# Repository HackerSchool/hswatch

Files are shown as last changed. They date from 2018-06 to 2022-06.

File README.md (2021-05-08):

# HSWatch

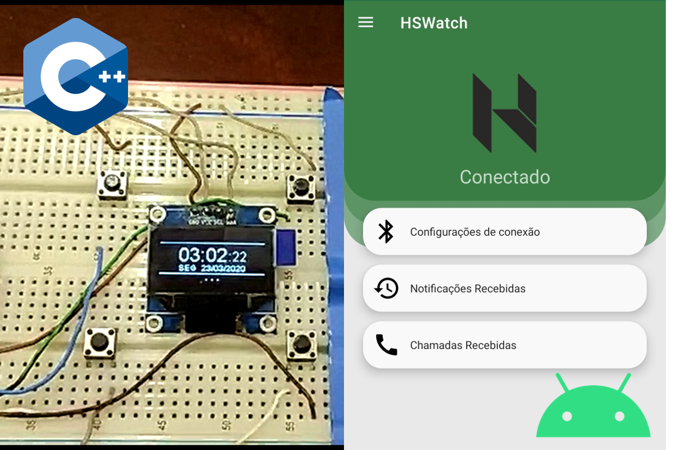
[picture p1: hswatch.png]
HSWatch


## Objective

This project aims to create a _diy_ smartwatch, open-source and programable using Arduino code style, so that hobbyists, students and hackers can contribute to this project and design their own smartwatch according to their tastes. Besides the watch it self this project also contains an Android companion app source code, that is also extendable so that the watch can accomodate more features.

## Features 

This are the features that are already implemented:
- Show a clock (hours, minutes, seconds, day, month, year, week day) regularly syncronized with the smartphone clock.
- Mirror notifications from the smartphone to the watch screen, vibrating each time a new one is received.
- Show notification history, blinking a RGB LED each time there is an unread message. (The LED blinks a diferent color for diferent types of notifications)
- Measure battery charge level of the smartwatch and show it on the main screen.
- Three adjustable alarm clocks. This alarms sound a buzzer and vibrate the watch.
- Stop watch and timer.
- Show 6 days weather forecast on watch screen, using the smartphone companion app as a gateway to online weather services.

The software was made to be easily extendable, feel free to add more features.

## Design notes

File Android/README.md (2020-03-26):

# HSWatch

GitHub para a aplicação HSWatch @ HackerSchool.

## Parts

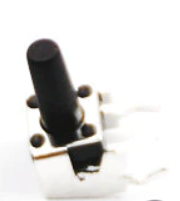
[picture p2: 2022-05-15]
docs/img/components/button.png

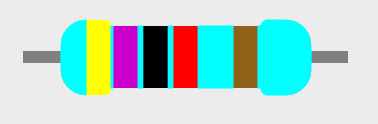
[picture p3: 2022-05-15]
docs/img/components/47kr.png

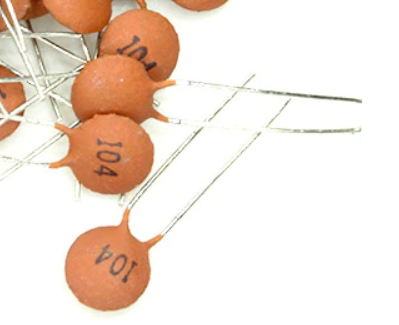
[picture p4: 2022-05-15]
docs/img/components/capacitor.png

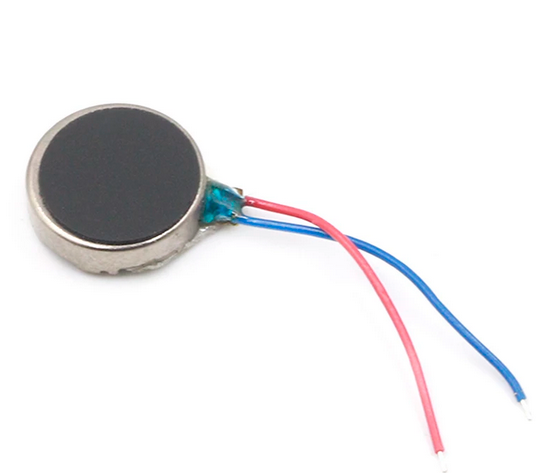
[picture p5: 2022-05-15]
docs/img/components/vibrator.png

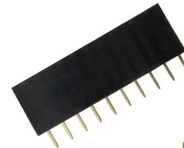
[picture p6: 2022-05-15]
docs/img/components/pin_header_ttgo.png

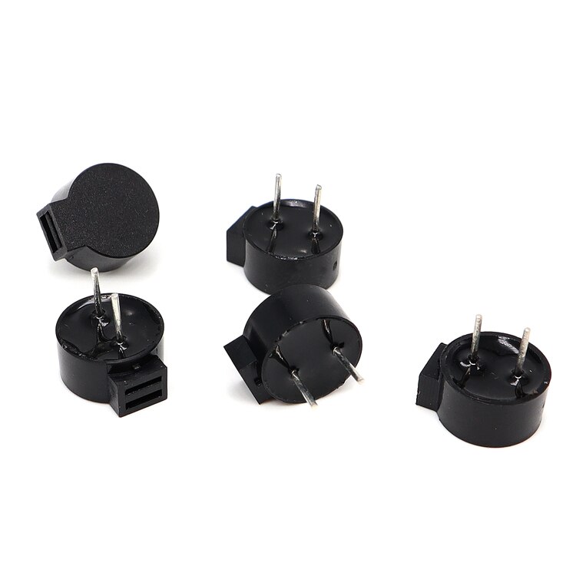
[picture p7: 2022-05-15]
docs/img/components/buzzer.jpg

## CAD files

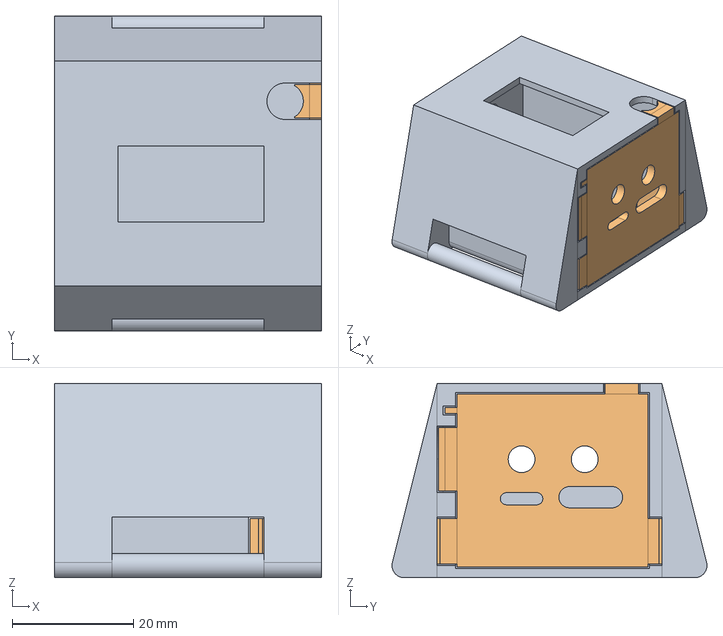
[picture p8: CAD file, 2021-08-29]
3D_Models/Assembly_hswatch.FCStd
44.0 x 51.9 x 32.0 mm
left
right (cover)

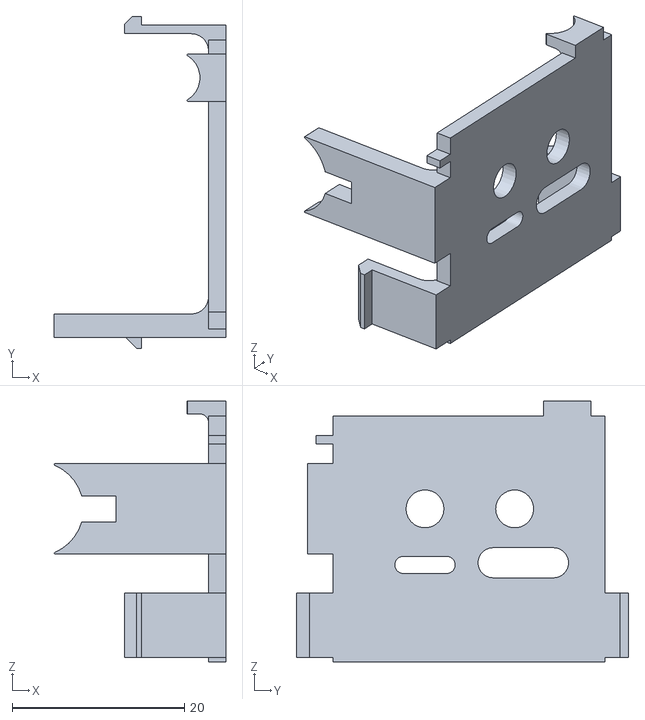
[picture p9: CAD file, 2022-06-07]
3D_Models/Case_Side_Right(Cover).stl
19.9 x 38.5 x 30.2

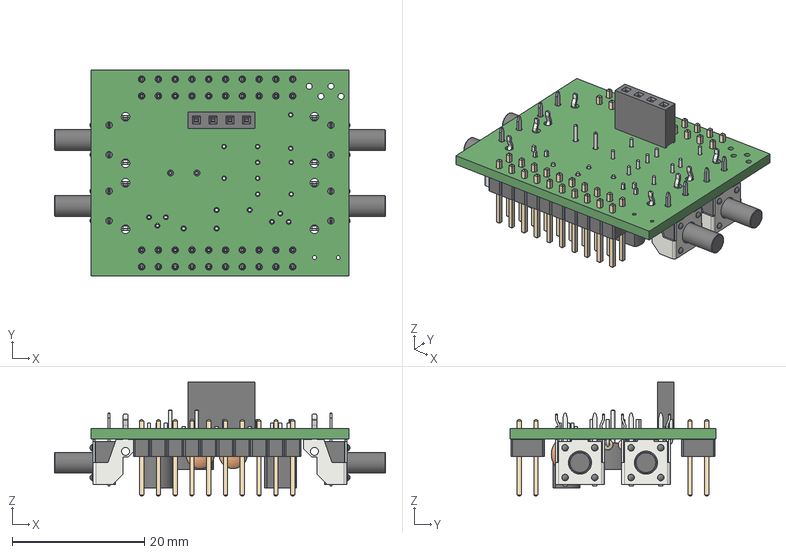
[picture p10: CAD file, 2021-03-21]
PCB/hswatch.step
50.1 x 31.2 x 17.2 mm

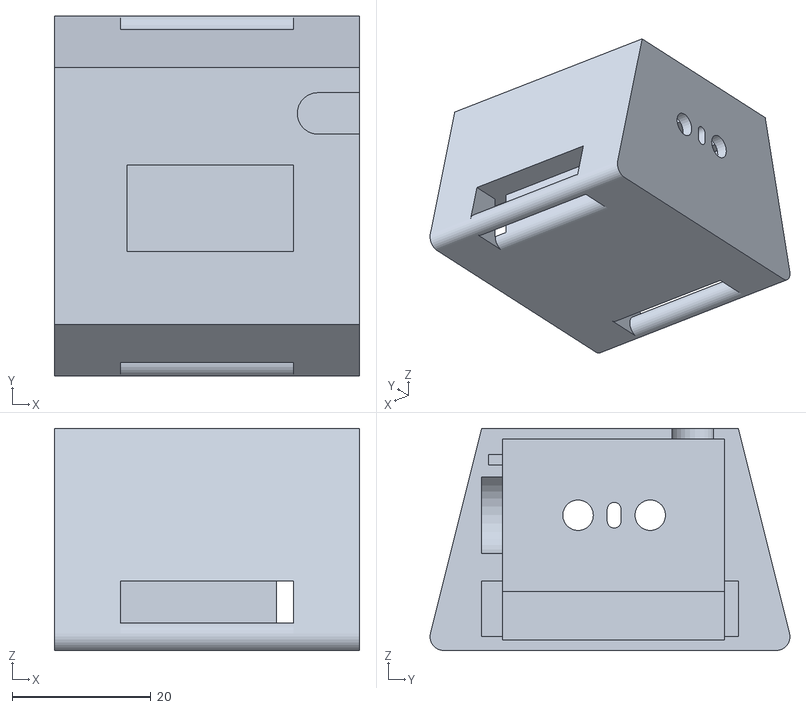
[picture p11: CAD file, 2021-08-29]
3D_Models/Case_Side_Left.stl
44.0 x 51.9 x 32.0

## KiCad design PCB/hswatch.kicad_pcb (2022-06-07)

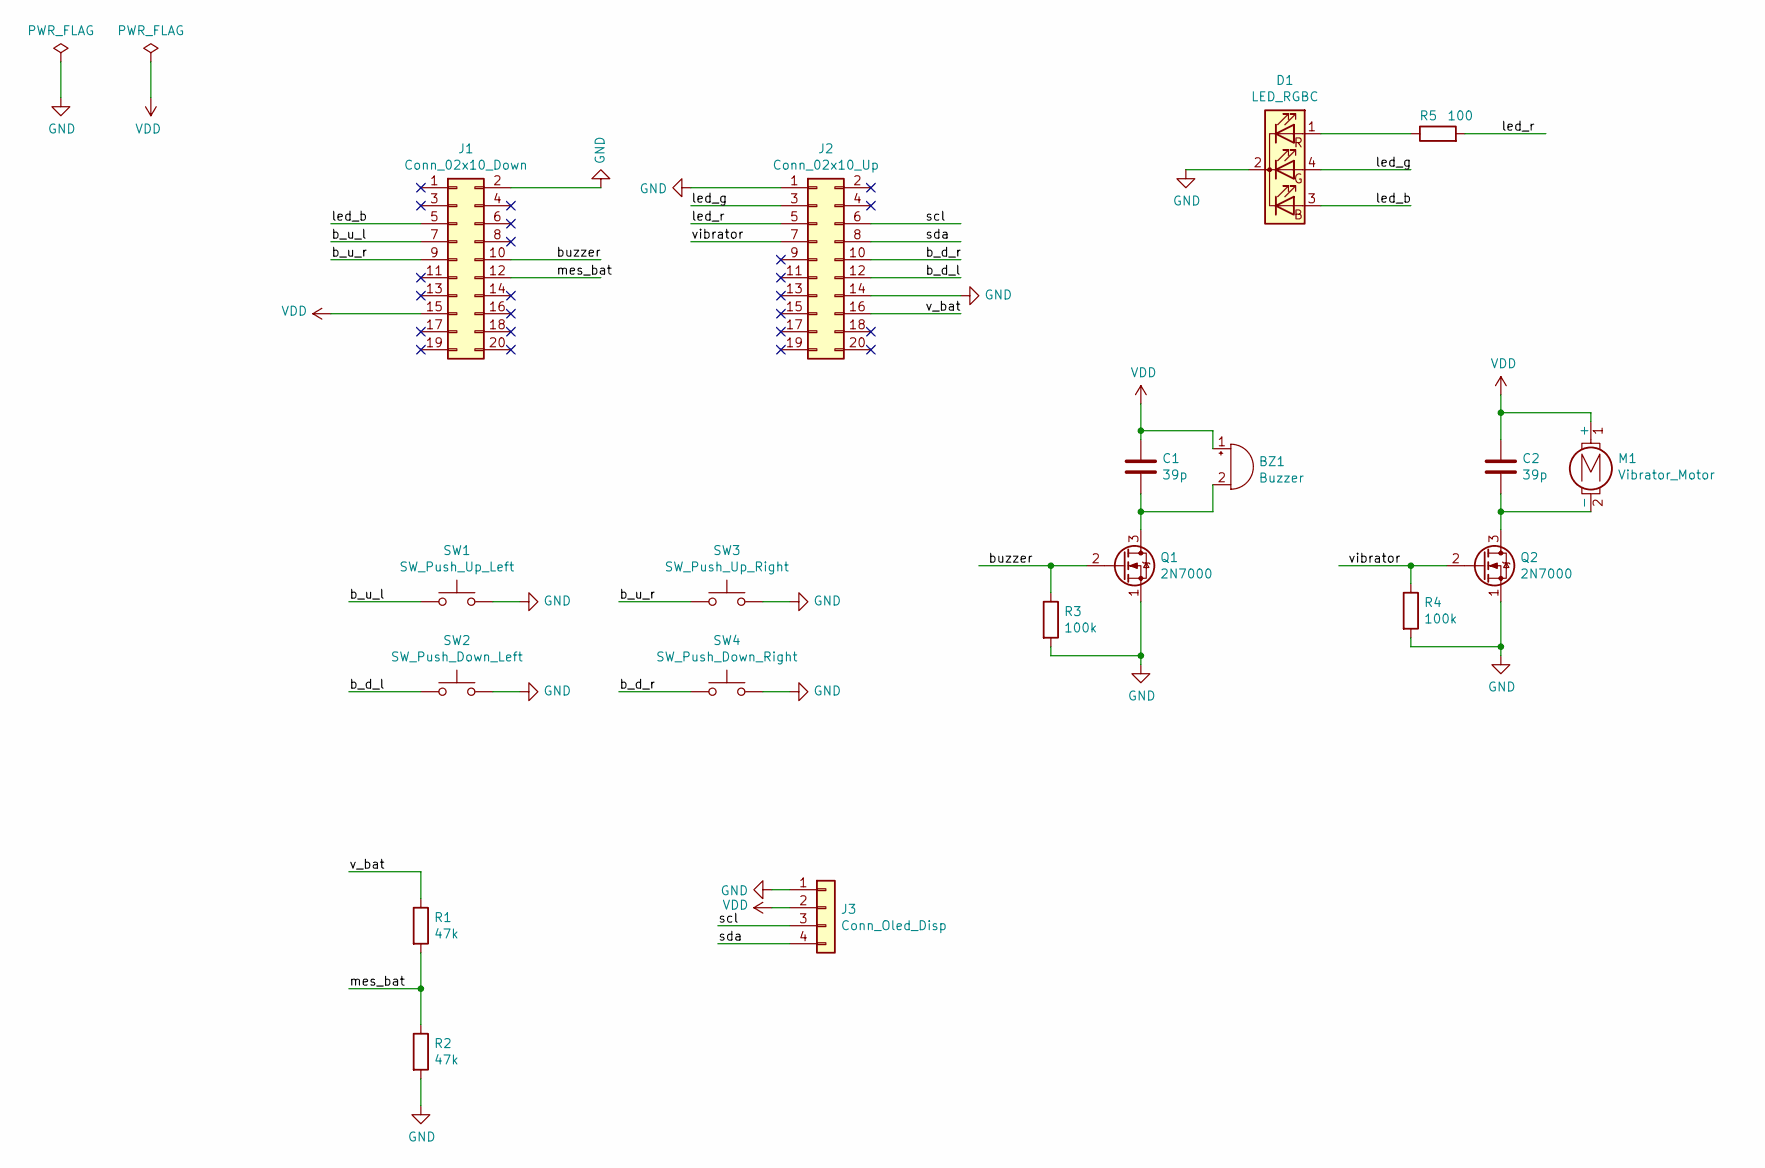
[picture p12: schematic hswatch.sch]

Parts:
BZ1: Buzzer; MagneticBuzzer_CUI_CST-931RP-A
C1, C2: 39p; C_Disc_D4.3mm_W1.9mm_P5.00mm
D1: LED_RGBC; LED_D5.0mm-4_RGB_Staggered_Pins
J1: Conn_02x10_Down; PinHeader_2x10_P2.54mm_Vertical
J2: Conn_02x10_Up; PinHeader_2x10_P2.54mm_Vertical
J3: Conn_Oled_Disp; PinSocket_1x04_P2.54mm_Vertical
M1: Vibrator_Motor; SolderWire-0.1sqmm_1x02_P3.6mm_D0.4mm_OD1mm
Q1, Q2: 2N7000; TO-92_HandSolder
R1, R2: 47k; R_Axial_DIN0204_L3.6mm_D1.6mm_P5.08mm_Horizontal
R3, R4: 100k; R_Axial_DIN0204_L3.6mm_D1.6mm_P5.08mm_Horizontal
R5: 100; R_Axial_DIN0204_L3.6mm_D1.6mm_P5.08mm_Horizontal
SW1: SW_Push_Up_Left; SW_Tactile_SPST_Angled_PTS645Vx83-2LFS
SW2: SW_Push_Down_Left; SW_Tactile_SPST_Angled_PTS645Vx83-2LFS
SW3: SW_Push_Up_Right; SW_Tactile_SPST_Angled_PTS645Vx83-2LFS
SW4: SW_Push_Down_Right; SW_Tactile_SPST_Angled_PTS645Vx83-2LFS

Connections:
/b_d_l: J2.12, SW2.1
/b_d_r: J2.10, SW4.1
/b_u_l: J1.7, SW1.1
/b_u_r: J1.9, SW3.1
/buzzer: J1.10, Q1.2 (G), R3.1
/led_b: D1.3 (BA), J1.5
/led_g: D1.4 (GA), J2.3
/led_r: J2.5, R5.2
/mes_bat: J1.12, R1.2, R2.1
/scl: J2.6, J3.3
/sda: J2.8, J3.4
/v_bat: J2.16, R1.1
/vibrator: J2.7, Q2.2 (G), R4.1
GND: D1.2 (K), J1.2, J2.1, J2.14, J3.1, Q1.1 (S), Q2.1 (S), R2.2, R3.2, R4.2, SW1.2, SW2.2, SW3.2, SW4.2
unnamed: BZ1.2 (+), C1.2, Q1.3 (D)
unnamed: C2.2, M1.2 (-), Q2.3 (D)
unnamed: D1.1 (RA), R5.1
VDD: BZ1.1 (-), C1.1, C2.1, J1.15, J3.2, M1.1 (+)

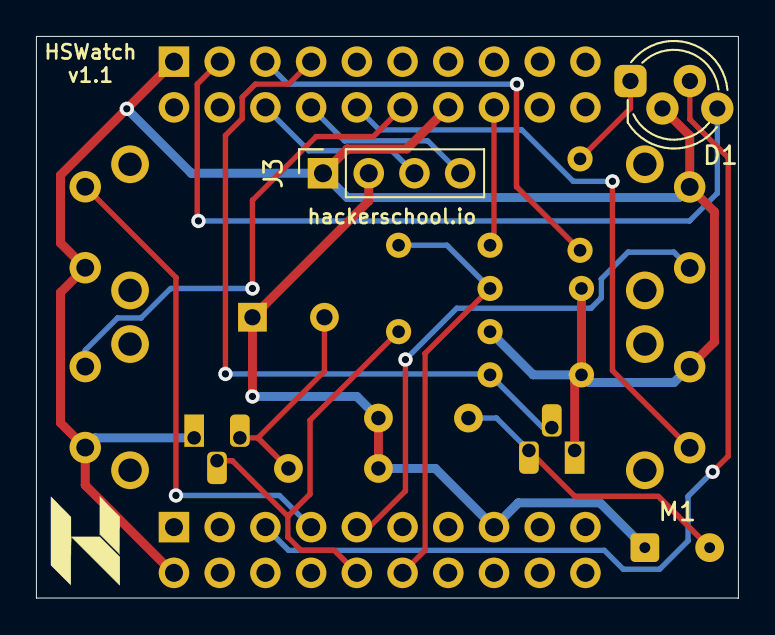
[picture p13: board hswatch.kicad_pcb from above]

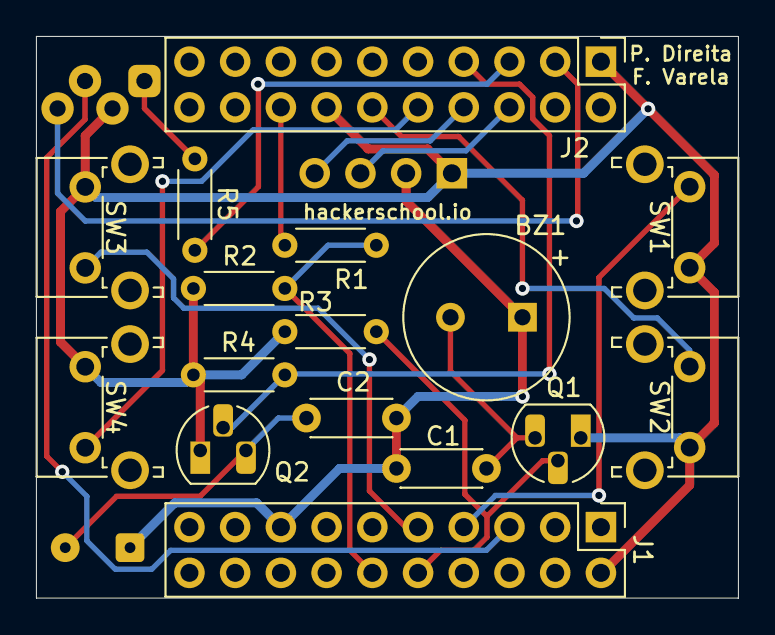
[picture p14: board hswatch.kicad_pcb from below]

Board: 2 copper layers, 39.0 x 31.2 mm, 19 parts (16 on the bottom side), 18 nets.

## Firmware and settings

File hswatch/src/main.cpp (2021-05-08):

#include <Arduino.h>
#include "communication.h"
#include "home.h"
#include "logo_hs.h"
#include <Wire.h>
#include <SSD1306Wire.h>
#include "queue_display.h"
#include "display.h"
#include "notification.h"
#include "menu.h"
#include "logo_app.h"
#include "vibrator.h"
#include "buzzer.h"
#include "led.h"
#include "app.h"
#include "battery.h"
#include "about.h"

//Include App go here
#include "timer.h"
#include "alarm.h"
#include "weather.h"
#include "flashlight.h"
#include "settings.h"

#define B_LEFT_UP 18
#define B_LEFT_DOWN 16
#define B_RIGHT_UP 19
#define B_RIGHT_DOWN 17

#define BT_BUFFER_SIZE 300
#define DEBOUNCE_TIME 50
#define DEBOUNCE_TIME2 50

TaskHandle_t bt_task_h, timer_task_h, b_left_up_task_h, b_left_down_task_h, b_right_up_task_h, b_right_down_task_h;

QueueHandle_t * queue_display;

hw_timer_t * timer = NULL;

SSD1306Wire screen(0x3c, SDA, SCL);

unsigned long debounce_left_up=0, debounce_left_down=0, debounce_right_up=0, debounce_right_down=0;

int number_of_times=0;
int number_of_times_r=0;

void bt_task(void*);
int init_display();
void IRAM_ATTR onTimer();
void timer_task(void*);

void IRAM_ATTR onPressBLeftUp();
void IRAM_ATTR onPressBLeftDown();
void IRAM_ATTR onPressBRightUp();
void IRAM_ATTR onPressBRightDown();
void b_left_up_task(void*);
void b_left_down_task(void*);
void b_right_up_task(void*);
void b_right_down_task(void*);


void setup() {

	Serial.begin(9600);

	pinMode(B_LEFT_UP, INPUT_PULLUP);
	pinMode(B_LEFT_DOWN, INPUT_PULLUP);
	pinMode(B_RIGHT_UP, INPUT_PULLUP);
	pinMode(B_RIGHT_DOWN, INPUT_PULLUP);

	init_bluetooth("HSWatch");
	init_led();
	init_display();
	init_vibrator();
	init_buzzer();
	init_battery();
	App::init_app();

	queue_display = new QueueHandle_t();

	*queue_display = xQueueCreate(15,sizeof(msg_queue_display));

	new Home("TIM","Home",NULL);
	new Notification("NOT","Notification",NULL);
	new About("Abo","About",NULL);
	
	//App Initialization goes here
	new Timer("CHR","Chronograph & Timer",logo_timer);
	new Alarm("ALA","Alarm", logo_alarm);
	new Weather("WEA","Weather", logo_weather);
	new FlashLight("FLA","Flashlight", logo_flashlight);
	new Settings("SET","Settings", logo_settings);
	
	new Menu("MEN","Menu",NULL);

	App::run_app("Home");

	xTaskCreate(bt_task,"bluetooth task",8192,NULL,1,&bt_task_h);
	xTaskCreate(timer_task,"timer task",8192,NULL,1,&timer_task_h);
	xTaskCreate(b_left_up_task,"button left up task",8192,NULL,1,&b_left_up_task_h);
	xTaskCreate(b_left_down_task,"button left down task",8192,NULL,1,&b_left_down_task_h);
	xTaskCreate(b_right_up_task,"button right up task",8192,NULL,1,&b_right_up_task_h);
	xTaskCreate(b_right_down_task,"button right down task",8192,NULL,1,&b_right_down_task_h);

	timer = timerBegin(0,80,true);
	timerAttachInterrupt(timer, &onTimer, true);
	timerAlarmWrite(timer, 1000000, true);
	timerAlarmEnable(timer);

	attachInterrupt(B_LEFT_UP, onPressBLeftUp, FALLING);
	attachInterrupt(B_LEFT_DOWN, onPressBLeftDown, FALLING);
	attachInterrupt(B_RIGHT_UP, onPressBRightUp, FALLING);
	attachInterrupt(B_RIGHT_DOWN, onPressBRightDown, FALLING);

}

void loop() {

	msg_queue_display msg;

	xQueueReceive(*queue_display, &msg, portMAX_DELAY);
	
	switch (msg.type)
	{
	case _clear:
		screen.clear();
		break;

	case _display:
		screen.display();
		break;

	case _drawRect:
		screen.drawRect(msg.a,msg.b,msg.c,msg.d);
		break;

	case _fillRect:
		screen.fillRect(msg.a,msg.b,msg.c,msg.d);
		break;

	case _drawHorizontalLine:
		screen.drawHorizontalLine(msg.a,msg.b,msg.c);
		break;
	
	case _drawString:
		screen.drawString(msg.a,msg.b,String(msg.s));
		break;

	case _drawStringMaxWidth:
		screen.drawStringMaxWidth(msg.a,msg.b,msg.c,String(msg.s));
		break;

	case _setTextAlignment:
		if(msg.a==0){
			screen.setTextAlignment(TEXT_ALIGN_LEFT);
		}else if(msg.a==1){
			screen.setTextAlignment(TEXT_ALIGN_CENTER);
		}else if(msg.a==2){
			screen.setTextAlignment(TEXT_ALIGN_RIGHT);
		}else{
			screen.setTextAlignment(TEXT_ALIGN_CENTER_BOTH);
		}
		break;

	case _drawXbm:
		screen.drawXbm(msg.a, msg.b, msg.c, msg.d, msg.image);
	
	default:
		if(msg.a==0){
			screen.setFont(ArialMT_Plain_10);
		}else if(msg.a==1){
			screen.setFont(ArialMT_Plain_16);
		}else{
			screen.setFont(ArialMT_Plain_24);
		}
		break;
	}
}

void bt_task(void* par_in){

	//Adafruit_SSD1306 * screen=(Adafruit_SSD1306 *)par_in;
	//init_display();
	Serial.println(App::app_search_by_id("TIM")->id);
	//App::app_search_by_id("TIM")->display();
	//screen->clear();
	//screen->display();
	//App::run_app("Home");
	Serial.println("ola");
	int len;
	char buf[BT_BUFFER_SIZE], aux[BT_BUFFER_SIZE]; 
	char *context, *m_id, delim[2]; 
	App* app_to_call;
	
	delim[0] = (char)0x03;
	delim[1] = '\0';

	while(1){
		len = receive_bt(buf,BT_BUFFER_SIZE);

		buf[len]='\0';
		Serial.print("buf=");
		Serial.println(buf);

		if(len<5)
			continue;

		strcpy(aux,buf+4);
		m_id = strtok_r(buf,delim,&context);

		if(m_id==NULL)
			continue;
		
		app_to_call = App::app_search_by_id(String(m_id));
		if(app_to_call!=NULL){
			app_to_call->bt_receive(aux);
		}
	}

}

int init_display(){

	Display::initDisplay();
	 
	screen.init();

	screen.flipScreenVertically();

	screen.clear();
	screen.drawXbm(
		(128  - LOGO_WIDTH ) / 2,
		(64 - LOGO_HEIGHT) / 2,
		LOGO_WIDTH, LOGO_HEIGHT, logo_hs);
	screen.display();
	delay(3000);

	return 0;
}

void IRAM_ATTR onTimer(){
	vTaskNotifyGiveFromISR(timer_task_h,NULL);
}

void timer_task(void*){
	while (1)
	{
		ulTaskNotifyTake(pdFALSE, portMAX_DELAY);
		App::call_timer();
		check_level_timer();
	}
}

void IRAM_ATTR onPressBLeftUp(){
	vTaskNotifyGiveFromISR(b_left_up_task_h,NULL);
}

void IRAM_ATTR onPressBLeftDown(){
	vTaskNotifyGiveFromISR(b_left_down_task_h,NULL);
}

void IRAM_ATTR onPressBRightUp(){
	vTaskNotifyGiveFromISR(b_right_up_task_h,NULL);
}

void IRAM_ATTR onPressBRightDown(){
	vTaskNotifyGiveFromISR(b_right_down_task_h,NULL);
}

void b_left_up_task(void*){
	while (1)
	{
		ulTaskNotifyTake(pdFALSE, portMAX_DELAY);

		if(millis()-DEBOUNCE_TIME>debounce_left_up){

			delay(DEBOUNCE_TIME2);

			if(!digitalRead(B_LEFT_UP)){

				debounce_left_up=millis();
				number_of_times++;
				Serial.print("L: ");
				Serial.println(number_of_times);

				App::curr_app()->but_up_left();
			}
		}
	}
}

void b_left_down_task(void*){
	while (1)
	{
		ulTaskNotifyTake(pdFALSE, portMAX_DELAY);

		if(millis()-DEBOUNCE_TIME>debounce_left_down){

			delay(DEBOUNCE_TIME2);

			if(!digitalRead(B_LEFT_DOWN)){

				debounce_left_down=millis();
				number_of_times--;
				Serial.print("L: ");
				Serial.println(number_of_times);

				App::curr_app()->but_down_left();
			}
		}
	}
}

void b_right_up_task(void*){
	while (1)
	{
		ulTaskNotifyTake(pdFALSE, portMAX_DELAY);

		if(millis()-DEBOUNCE_TIME>debounce_right_up){

			delay(DEBOUNCE_TIME2);

			if(!digitalRead(B_RIGHT_UP)){

				debounce_right_up=millis();
				number_of_times_r++;
				Serial.print("R: ");
				Serial.println(number_of_times_r);

				App::curr_app()->but_up_right();
			}
		}
	}
}

void b_right_down_task(void*){
	while (1)
	{
		ulTaskNotifyTake(pdFALSE, portMAX_DELAY);

		if(millis()-DEBOUNCE_TIME>debounce_right_down){

			delay(DEBOUNCE_TIME2);

			if(!digitalRead(B_RIGHT_DOWN)){

				debounce_right_down=millis();
				number_of_times_r--;
				Serial.print("R: ");
				Serial.println(number_of_times_r);

				App::curr_app()->but_down_right();
			}
		}
	}
}

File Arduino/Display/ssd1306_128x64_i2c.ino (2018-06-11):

/*********************************************************************
This is an example for our Monochrome OLEDs based on SSD1306 drivers

  Pick one up today in the adafruit shop!
  ------> http://www.adafruit.com/category/63_98

This example is for a 128x64 size display using I2C to communicate
3 pins are required to interface (2 I2C and one reset)

Adafruit invests time and resources providing this open source code, 
please support Adafruit and open-source hardware by purchasing 
products from Adafruit!

Written by Limor Fried/Ladyada  for Adafruit Industries.  
BSD license, check license.txt for more information
All text above, and the splash screen must be included in any redistribution
*********************************************************************/

#include <SPI.h>
#include <Wire.h>
#include <Adafruit_GFX.h>
#include <Adafruit_SSD1306.h>

#define OLED_RESET 4
Adafruit_SSD1306 display(OLED_RESET);

#define NUMFLAKES 10
#define XPOS 0
#define YPOS 1
#define DELTAY 2


#define LOGO16_GLCD_HEIGHT 16 
#define LOGO16_GLCD_WIDTH  16 
static const unsigned char PROGMEM logo16_glcd_bmp[] =
{ B00000000, B11000000,
  B00000001, B11000000,
  B00000001, B11000000,
  B00000011, B11100000,
  B11110011, B11100000,
  B11111110, B11111000,
  B01111110, B11111111,
  B00110011, B10011111,
  B00011111, B11111100,
  B00001101, B01110000,
  B00011011, B10100000,
  B00111111, B11100000,
  B00111111, B11110000,
  B01111100, B11110000,
  B01110000, B01110000,
  B00000000, B00110000 };

//#if (SSD1306_LCDHEIGHT != 64)
//#error("Height incorrect, please fix Adafruit_SSD1306.h!");
//#endif

void setup()   {                
  Serial.begin(9600);

  // by default, we'll generate the high voltage from the 3.3v line internally! (neat!)
  display.begin(SSD1306_SWITCHCAPVCC, 0x3D);  // initialize with the I2C addr 0x3D (for the 128x64)
  // init done
  
  // Show image buffer on the display hardware.
  // Since the buffer is intialized with an Adafruit splashscreen
  // internally, this will display the splashscreen.
  display.display();
  delay(2000);

  // Clear the buffer.
  display.clearDisplay();

  // draw a single pixel
  display.drawPixel(10, 10, WHITE);
  // Show the display buffer on the hardware.
  // NOTE: You _must_ call display after making any drawing commands
  // to make them visible on the display hardware!
  display.display();
  delay(2000);
  display.clearDisplay();

  // draw many lines
  testdrawline();
  display.display();
  delay(2000);
  display.clearDisplay();

  // draw rectangles
  testdrawrect();
  display.display();
  delay(2000);
  display.clearDisplay();

  // draw multiple rectangles
  testfillrect();
  display.display();
  delay(2000);
  display.clearDisplay();

  // draw mulitple circles
  testdrawcircle();
  display.display();
  delay(2000);
  display.clearDisplay();

  // draw a white circle, 10 pixel radius
  display.fillCircle(display.width()/2, display.height()/2, 10, WHITE);
  display.display();
  delay(2000);
  display.clearDisplay();

  testdrawroundrect();
  delay(2000);
  display.clearDisplay();

  testfillroundrect();
  delay(2000);
  display.clearDisplay();

  testdrawtriangle();
  delay(2000);
  display.clearDisplay();
   
  testfilltriangle();
  delay(2000);
  display.clearDisplay();

  // draw the first ~12 characters in the font
  testdrawchar();
  display.display();
  delay(2000);
  display.clearDisplay();

  // draw scrolling text
  testscrolltext();
  delay(2000);
  display.clearDisplay();

  // text display tests
  display.setTextSize(1);
  display.setTextColor(WHITE);
  display.setCursor(0,0);
  display.println("Hello, world!");
  display.setTextColor(BLACK, WHITE); // 'inverted' text
  display.println(3.141592);
  display.setTextSize(2);
  display.setTextColor(WHITE);
  display.print("0x"); display.println(0xDEADBEEF, HEX);
  display.display();
  delay(2000);
  display.clearDisplay();

  // miniature bitmap display
  display.drawBitmap(30, 16,  logo16_glcd_bmp, 16, 16, 1);
  display.display();
  delay(1);

  // invert the display
  display.invertDisplay(true);
  delay(1000); 
  display.invertDisplay(false);
  delay(1000); 
  display.clearDisplay();

  // draw a bitmap icon and 'animate' movement
  testdrawbitmap(logo16_glcd_bmp, LOGO16_GLCD_HEIGHT, LOGO16_GLCD_WIDTH);
}


void loop() {
  
}


void testdrawbitmap(const uint8_t *bitmap, uint8_t w, uint8_t h) {
  uint8_t icons[NUMFLAKES][3];
 
  // initialize
  for (uint8_t f=0; f< NUMFLAKES; f++) {
    icons[f][XPOS] = random(display.width());
    icons[f][YPOS] = 0;
    icons[f][DELTAY] = random(5) + 1;
    
    Serial.print("x: ");
    Serial.print(icons[f][XPOS], DEC);
    Serial.print(" y: ");
    Serial.print(icons[f][YPOS], DEC);
    Serial.print(" dy: ");
    Serial.println(icons[f][DELTAY], DEC);
  }

  while (1) {
    // draw each icon
    for (uint8_t f=0; f< NUMFLAKES; f++) {
      display.drawBitmap(icons[f][XPOS], icons[f][YPOS], bitmap, w, h, WHITE);
    }
    display.display();
    delay(200);
    
    // then erase it + move it
    for (uint8_t f=0; f< NUMFLAKES; f++) {
      display.drawBitmap(icons[f][XPOS], icons[f][YPOS], bitmap, w, h, BLACK);
      // move it
      icons[f][YPOS] += icons[f][DELTAY];
      // if its gone, reinit
      if (icons[f][YPOS] > display.height()) {
        icons[f][XPOS] = random(display.width());
        icons[f][YPOS] = 0;
        icons[f][DELTAY] = random(5) + 1;
      }
    }
   }
}


void testdrawchar(void) {
  display.setTextSize(1);
  display.setTextColor(WHITE);
  display.setCursor(0,0);

  for (uint8_t i=0; i < 168; i++) {
    if (i == '\n') continue;
    display.write(i);
    if ((i > 0) && (i % 21 == 0))
      display.println();
  }    
  display.display();
  delay(1);
}

void testdrawcircle(void) {
  for (int16_t i=0; i<display.height(); i+=2) {
    display.drawCircle(display.width()/2, display.height()/2, i, WHITE);
    display.display();
    delay(1);
  }
}

void testfillrect(void) {
  uint8_t color = 1;
  for (int16_t i=0; i<display.height()/2; i+=3) {
    // alternate colors
    display.fillRect(i, i, display.width()-i*2, display.height()-i*2, color%2);
    display.display();
    delay(1);
    color++;
  }
}

void testdrawtriangle(void) {
  for (int16_t i=0; i<min(display.width(),display.height())/2; i+=5) {
    display.drawTriangle(display.width()/2, display.height()/2-i,
                     display.width()/2-i, display.height()/2+i,
                     display.width()/2+i, display.height()/2+i, WHITE);
    display.display();
    delay(1);
  }
}

void testfilltriangle(void) {
  uint8_t color = WHITE;
  for (int16_t i=min(display.width(),display.height())/2; i>0; i-=5) {
    display.fillTriangle(display.width()/2, display.height()/2-i,
                     display.width()/2-i, display.height()/2+i,
                     display.width()/2+i, display.height()/2+i, WHITE);
    if (color == WHITE) color = BLACK;
    else color = WHITE;
    display.display();
    delay(1);
  }
}
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

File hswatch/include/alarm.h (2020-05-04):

#include "app.h"
#include "tools.h"

class Alarm: public App {

	public:

		void start();
		void display();
		void but_up_left();
		void but_up_right();
		void but_down_left();
		void but_down_right();
		void timer_1s();

		Alarm(String,String,const unsigned char*);

	private:

		enum State {alarm1_home, alarm1_hours, alarm1_minutes, alarm2_home, alarm2_hours, alarm2_minutes, alarm3_home, alarm3_hours, alarm3_minutes} state;
		timestamp alarm1_timestamp, alarm2_timestamp, alarm3_timestamp, timer_timestamp;
		SemaphoreHandle_t mutex_alarm1, mutex_alarm2, mutex_alarm3;
		bool blink, alarm1, alarm2, alarm3, alarm1_ringing, alarm2_ringing, alarm3_ringing;
		bool alarm_off();

		unsigned char vibration_pattern_power[2] = {255,0};
		unsigned int vibration_pattern_time[2] = {2000,1000};
		unsigned char vibration_pattern_size = 2;
		unsigned char vibration_pattern_repeat = 5;

		TaskHandle_t alarm_vibrator_task = NULL;

		unsigned char buzzer_pattern_power[8] = {255,0,255,0,255,0,255,0};
		unsigned int buzzer_pattern_time[8] = {500,500,500,500,500,500,500,1500};
		unsigned int buzzer_pattern_frequency[8] = {2000,2000,2000,2000,2000,2000,2000,2000};
		unsigned char buzzer_pattern_size = 8;
		unsigned char buzzer_pattern_repeat = 3;

		TaskHandle_t alarm_buzzer_task = NULL;
};

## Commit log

2018-05-14 HsWatch first commit - Testes BT, Material
    -> Documentos do Projecto com o material necessario e breve descrição
    -> Set-up da comunicação entre o modulo bluetooth e o arduino, sofware para o Arduino que permite fazer de repetidor bluetooth
2018-06-11 Documentação da library do display
    Documentação oficial da adafruit para a library "Adafruit GFX Library"
2018-11-26 Teste do ESP32
2018-11-27 Melhor nome para a repo partihada
2018-12-02 LED a piscar por Bluetooth
2019-08-08 Major developmente in HSwatch project
    Core files of the ESP32 watch OS were uploaded. Issues found on the multithread capability of the OLED display library.
2019-08-10 Change of the display library
    The display library was changed to the thingpulse library instead of the adafruit one, however there is still issues regarding to the multithreading capability of the display library. This may be due to the I2C default library of the arduino framework, called wire.h
    [main.cpp]
2019-08-16 Multithread capability of display library added
    The main thread handles the display and receives requests from other threads through a queue. All the display library was reimplemented in order to cope with that queue.
2019-08-20 Add timer functionality
    Clock is already working, and can be updated via bluetooth. The system is prepared to receive other apps that need to have a notion of time.
2020-03-20 Display was made thread safe
2020-03-20 Add button functionality
2020-03-27 Criado o fragmento principal
    Foi criado o fragmento principal onde tem como função mostrar as funcionalidades e estado que a app pode dar ao relógio. Falta reorginazação da atividade.
2020-03-29 Conection's Thread implemented
2020-04-03 Create main menu
    Main menu tested
    timer and alarm app logos created
2020-04-04 Timer App added & Several minor changes to make the code more modular
    In fact the App is called Chronograph & Timer, because it is able to simultaneusly do those two funcions.
2020-05-08 Add led functionality and update to weather app
    In additation small changes were made the bluetooth communication library in order to make it more robust.
2020-05-12 Led module complete
    The notification app makes use of the led module fade function having a diferent color for each type of notification
2020-05-19 Add battery level and bt connection indicator functionality
2020-05-19 Add vibration when notification is received
    [notification.h]
2020-06-11 Change led pinout
2020-12-07 Update to battery library to adapt to TTGO T7 v1.3 board
2020-12-22 The GPS Switch is workjing as it should - OFF = Choosen City
2021-02-02 Calibrate battery measurement system
2021-03-21 Added 3D_Models directory
    * With 3D model for the case and internal circuits
    [Case_Side_Left.FCStd, Eletronics_Interior.step]
2021-03-24 Made enclosure of the 3d model
    [Case_Side_Left.FCStd, Case_Side_Right(Cover).FCStd, Case_Side_Right(Cover)medidas.FCStd]
2021-03-24 Surpass conflict on Case:_Side_Left file
    [Case_Side_Left.FCStd]
2021-03-24 Update case cover
    [Case_Side_Right(Cover)medidas.FCStd]
2021-03-24 Added Steps
    [Case_Side_Left.step, Case_Side_Right.step]
2021-03-24 Create Assembly of hswatch & fix modeling issues
    [Assembly_hswatch.FCStd, Case_Side_Right(Cover).FCStd, Case_Side_Right.step]
2021-03-25 Update Assembly 3D
    [Assembly_hswatch.FCStd]
2021-03-26 New version of 3D model
    Stronger bracelet support, prettier design
    [Assembly_hswatch.FCStd, Assembly_hswatchv2.FCStd, Case_Side_Leftv2.FCStd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]
2021-03-26 3D model, design incompatibilities fixes
    [Assembly_hswatchv2.FCStd, Case_Side_Leftv2.stl]
2021-03-30 Update of 3D model, small details to make the model fit better with the rest of the system
    [Assembly_hswatchv2.FCStd, Assembly_hswatchv2b.FCStd, Case_Side_Leftv2a.stl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]
2021-04-23 First interation to the bluetooth device reconection
    Need tests to garantee that this method works
2021-04-29 Led library updates
    Supports prioritizing of led tasks. Now a new led task cancels the previous if its high priority or its ignored otherwise instead of being put in a waiting list
2021-04-30 Add Flashligh app and fix minor bugs in led library
    Some changes were also made in the color of the led blinking in notifications
    [led.cpp, led.h, main.cpp]
2021-05-08 Add settings app and modify device libraries
2021-06-06 Prepare for notifications filter
2021-06-20 Notification Filter first iteration version
2021-06-29 Added a thread to test the connection in every 30 seconds
2021-07-21 Trace one test run
2021-07-23 App ready for the first deployment ( Close #17 & Close #16 & Close #14 & Close #12 )
    Possible it should have many commits accumulated on this one, but vacations were in the way and I completely forgot. My apologies for any inconvinience!
    [fragment_app_setup_start.xml, fragment_setup_app.xml]
2021-08-01 Add vibrator adaptor
    [Vibrator_Adapter.FCStd, Vibrator_Adapter.stl]
2021-08-03 Increase catilever size
    [Assembly_hswatchv2.FCStd, Assembly_hswatchv2b.FCStd]
2021-08-29 Change screen hole size in 3D model
    [Assembly_hswatchv2b.FCStd, Case_Side_Left.stl, Case_Side_Right(Cover).stl]
2021-12-30 API Key and Connection Switch fixed (Closes #19 )
    Now the API Key is requested to the user and tested if it works.
    Aswell the connection switch now tell exactly if there is a connection or not.
2022-05-18 Android Studio Update
    Added the files modified by the current Android Studio's update
2022-05-19 Android Manifest updated to the current compileSDK version
    Since there were some changes in the previous commit in respect of the dependencies version, the manifest was necessary to change to adjust those changes, which was not committed up until now.
    Hopefully, these changes solve this problem and the following commits will be just the advance of the module.
2022-05-23 Update 3D model folder
    [Assembly_hswatch.FCStd, Assembly_hswatchv2.FCStd, Assembly_hswatchv2b.FCStd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]
2022-06-07 Add PCB design
    [hswatch-B_Cu.gbl, hswatch-B_Mask.gbs, hswatch-B_Paste.gbp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]
2022-06-07 HSWatch connection submodule implemented
    The submodule for the bluetooth connection is now complete and ready for tests. Therefore, this submodule will be, ideally, a gitsubmodule of a repository, which will make, possibly, in the future co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
    As for the main changes in this commit. This one is just a collective addition and copying of existing files from the bluetooth connection - such as MainService (now HSWService in the submodule) or t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
